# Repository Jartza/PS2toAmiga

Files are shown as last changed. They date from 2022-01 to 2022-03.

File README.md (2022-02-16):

# PS2toAmiga
Simple ATTiny85 based PS/2 to Amiga keyboard protocol converter that fits inside the keyboard.

The project was born as an idea to get small and color-matching keyboard to my old
Commodore Amiga CD32 console, in order to make it more Amiga-like, in use with
TerribleFire 330. I found few projects around The Net which did the same thing but some
of them used old and almost unobtainable ICs with closed firmware and some didn't work
that well.

Many projects used just way too big chip for the job, which I felt was a waste of precious
silicon, as you only need 2 input and 2 output pins for the job - ATTiny85 was chosen as
it's one of my favorite "all 'round" chip for simple tasks.

I wanted the adapter to sit inside the keyboard and use the CD32 AUX-connector (PS/2 style
mini-DIN) as-is for cable.

Of course the keyboard protocol is the same in all Amigas, the pinouts just differ, so this
project can be used to create replacement keyboard for the lost one to your bigger Amigas
as well (like Amiga 2000, 3000 & 4000 etc.)

## How it works

PS/2 keyboard protocol in it's basic level isn't that hard, it is bidirectional synchronous
serial port with clock (CLK) and data (DATA) lines, communicating with PS/2 keyboard using
microcontroller has been done multiple times already - which is why I chose to use
PS2KeyAdvanced library for Arduino to handle that task - I didn't want to re-invent the wheel,
and I had already used PS2KeyAdvanced in earlier projects as well. It also has nice support
for Caps Lock, Num Lock etc.

The keycodes read from PS/2 keyboard using PS2KeyAdvanced are then [translated to the respective
Amiga keycode](convert_table.h) and sent to wire, using
[Amiga keyboard protocol](http://amigadev.elowar.com/read/ADCD_2.1/Hardware_Manual_guide/node0172.html).

The converter-code also keeps track of user pressing CTRL-Amiga-Amiga simultaneously and
implements [resetting the Amiga](http://amigadev.elowar.com/read/ADCD_2.1/Hardware_Manual_guide/node0179.html)
when those keys are pressed. 

There are two different layouts, selectable with Scroll Lock (when Scroll Lock LED is on, second
layout is in use). In first layout, Windows/Menu-keys are mapped to respective
Amiga-keys on both sides of the space bar, Alt-keys are mapped to respective Amiga versions. 
On second layout, Left CTRL is mapped to CTRL, Right CTRL to ALT, ALT to Right Amiga-key. Also
on second layout, F11 and F12 are mapped to Left and Right Amiga-keys.

Mofifying the keyboard mapping should be pretty straight forward, in the table the comment after
keycode denotes the respective key on PS/2 keyboard and the Amiga keycode can be checked from
[this image](images/amigakeys.png). Do not remove values from the table, and do not change the 
order of the items! Only change the HEX Amiga keycode, before the comment.

Code itself is "quick'n'dirty" -style but should be pretty much commented out so you can modify
the internals of it to your own needs - if you have any.

## Installing

See [PS2KeyAdvanced](https://github.com/techpaul/PS2KeyAdvanced) project for install instructions,
for some reason the version 1.0.9 failed to install into my pretty recent Arduino install, but
version 1.0.8 worked as well.

For ATTiny85 support I used [ATTinyCore](https://github.com/SpenceKonde/ATTinyCore), again check
their respective site for install instructions to your Arduino IDE.

After installing ATTinyCore and PS2KeyAdvanced, load the project into your Arduino IDE and 
select following settings:

- **Board:** ATtiny24/45/85 (No bootloader)
- **Chip:** ATtiny85
- **Clock Source**: 16 MHz (PLL)
- **TImer 1 Clock:** CPU frequency
- **LTO:** Enabled
- **millis():** Enabled

#### Steps to install to ATTiny85:

Use whatever ISP programmer you have. I used cheap USBASP programmer with 10 -> 6 pin adapter cable,
having header pins in ISP connector and then pushing the connector into ISP holes (no header soldered)
and keeping them tilted in an angle during programming.

1. Tools -> Burn bootloader (actually only sets fuses, and enables 16MHz PLL clock)
2. Sketch -> Verify/Compile
3. Upload using programmer

You should be done now, if not, verify your programmer connections. I also have had issue sometimes
programming the new parts, which are set to 1MHz default in factory - you might need to change your
Arduino settings to slow down the programmer for Fuse burning.

## Connecting the adapter

Wiring the keyboard to your Amiga and PCB should be pretty obvious in the following diagram:

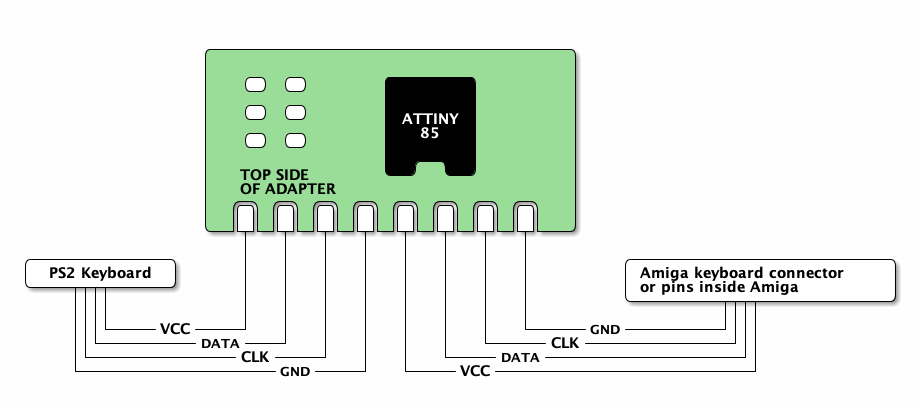
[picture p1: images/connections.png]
Connections


If that is not clear enough, the underside of the PCB has each pin function named.

Several Amigas have different pinouts, Google is your friend here.

**Word of warning:** if you think of re-using the PS/2 keyboard cable, be warned that most of
the keyboards only have 4-wire cable in them and probably the necessary pins are not connected
at all (at least if the Amiga you want to connect to has mini-DIN style keyboard connector).
I solved this issue by ordering PS/2 extension cable and just cutting off the female plug and
then using multimeter to solve cable colors to pins connection. Those extension cables usually
have all the 6 wires connected and it's much easier to use them than to solder those pesky
mini-DIN connectors.

## PCB

PCB files are in [pcb](pcb/) -folder, also including [gerbers](pcb/gerbers/), if you just want
to order the PCB. Schematics are respectively in [schematics](schematics/) -folder.
Bill of Materials, [BOM](schematics/BOM.txt) is also provided.

PCB and Schematics were designed using Eagle 9.6.1 free edition.

### Top side:
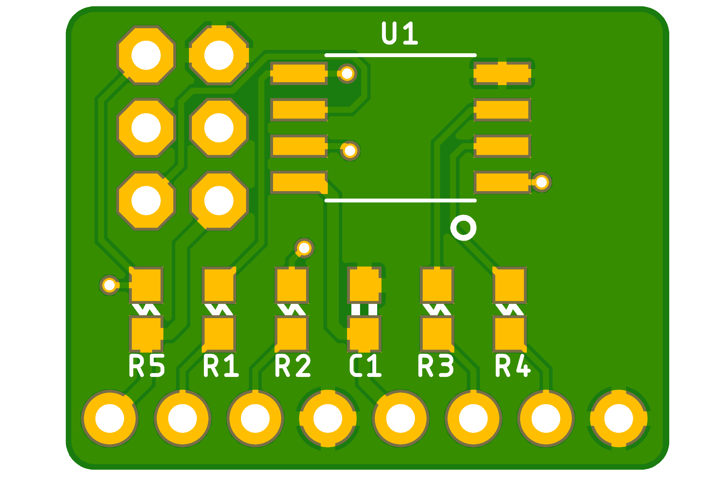
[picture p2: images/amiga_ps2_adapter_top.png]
PCB-TOP


### Bottom side:
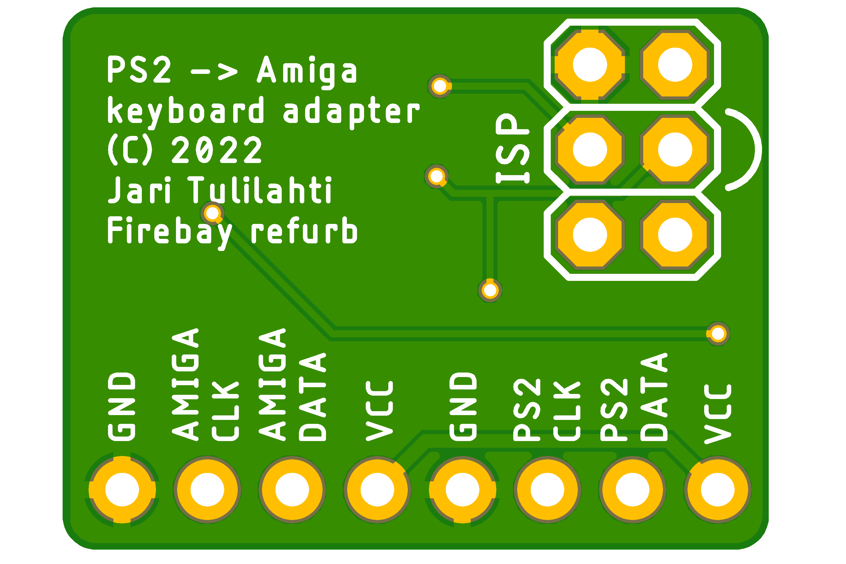
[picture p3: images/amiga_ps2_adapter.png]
PCB-BOTTOM


### Other

Please report any [issues](https://github.com/Jartza/PS2toAmiga/issues) you find with the code!

You can also participate in [discussions](https://github.com/Jartza/PS2toAmiga/discussions) without opening an issue. All enhancement ideas, questions etc. are welcome.

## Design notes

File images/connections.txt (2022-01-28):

                  /------------------------------------\
                  |                               cGRE |
                  |   /-\ /-\       /--------\         |
                  |   \-/ \-/       |        |         |
                  |   /-\ /-\       |cBLK    |         |
                  |   \-/ \-/       | ATTINY |         |
                  |   /-\ /-\       |   85   |         |
                  |   \-/ \-/       |        |         |
                  |                 |  /--\  |         |
                  |   TOP SIDE      \--/  \--/         |
                  |   OF ADAPTER                       |
                  |  /-\ /-\ /-\ /-\ /-\ /-\ /-\ /-\   |
                  |  | | | | | | | | | | | | | | | |   |
                  \--+++-+++-+++-+++-+++-+++-+++-+++---/
                      |   |   |   |   |   |   |   |
/--------------\      |   |   |   |   |   |   |   |         /--------------------------\
| PS2 Keyboard |      |   |   |   |   |   |   |   |         | Amiga keyboard connector |
\----++++------/      |   |   |   |   |   |   |   |         | or pins inside Amiga     |
     ||||             |   |   |   |   |   |   |   |         \---------++++-------------/
     ||||             |   |   |   |   |   |   |   |                   ||||
     |||+-----VCC-----+   |   |   |   |   |   |   +------GND----------+|||
     ||+----------DATA----+   |   |   |   |   +------CLK---------------+||
     |+---------------CLK-----+   |   |   +-----DATA--------------------+|
     +--------------------GND-----+   +-----VCC--------------------------+

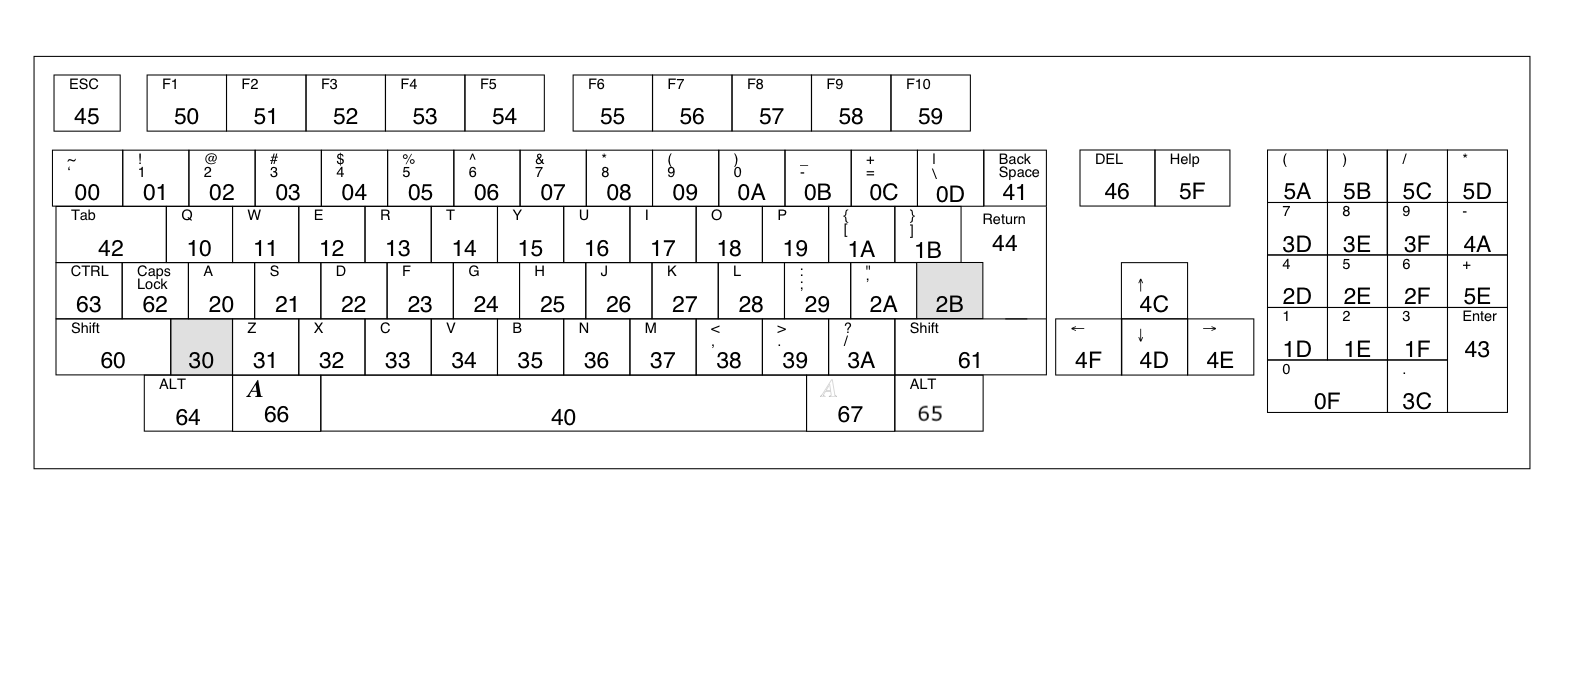
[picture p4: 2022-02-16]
images/amigakeys.png

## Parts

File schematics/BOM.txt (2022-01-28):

Bill of materials for PS2 to Amiga keyboard converter using ATTiny85
====================================================================

Designator                  Part                        Footprint
----------                  ----                        ---------
 U1                         ATTINY85-20SUR              SOIC-8
 R1,R2,R3,R4                Resistor 22-47 ohms         0603
 R5                         Resistor 4.7-10 kohms       0603
 ISP                        2x3 pinheader (NP)          2.54mm pitch
 J2                         1x8 pinheader (NP)          2.54mm pitch
 C1                         Ceramic capacitor 0.1 uF    0603

 NOTE:

 (NP) parts = Not Populated.

 ISP header is only used for programming (from the bottom side of the board!)
 and probably doesn't need to be populated, just press programming cable
 with header pin inserts into the connector holes and tilt a bit during
 ATTiny85 ISP programming.

 J2 is for keyboard connection but as probably this will sit inside the
 keyboard (or in the middle of cable inside stress relief box) you will
 most probably solder the keyboard wires directly to the header.

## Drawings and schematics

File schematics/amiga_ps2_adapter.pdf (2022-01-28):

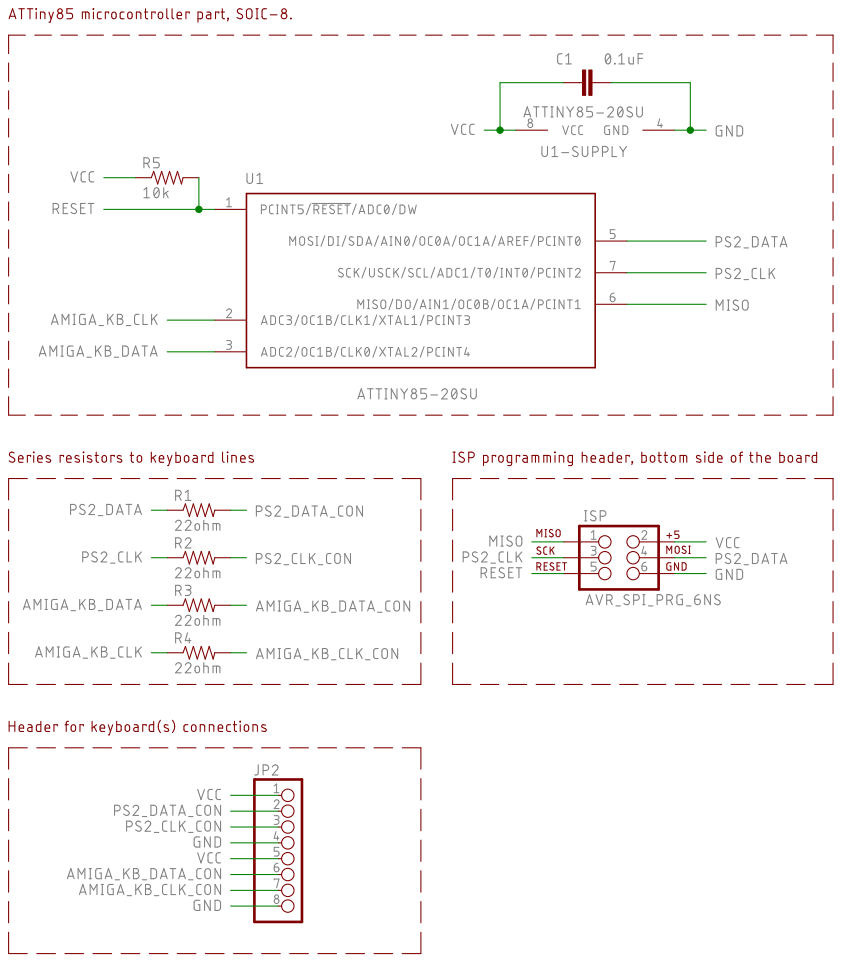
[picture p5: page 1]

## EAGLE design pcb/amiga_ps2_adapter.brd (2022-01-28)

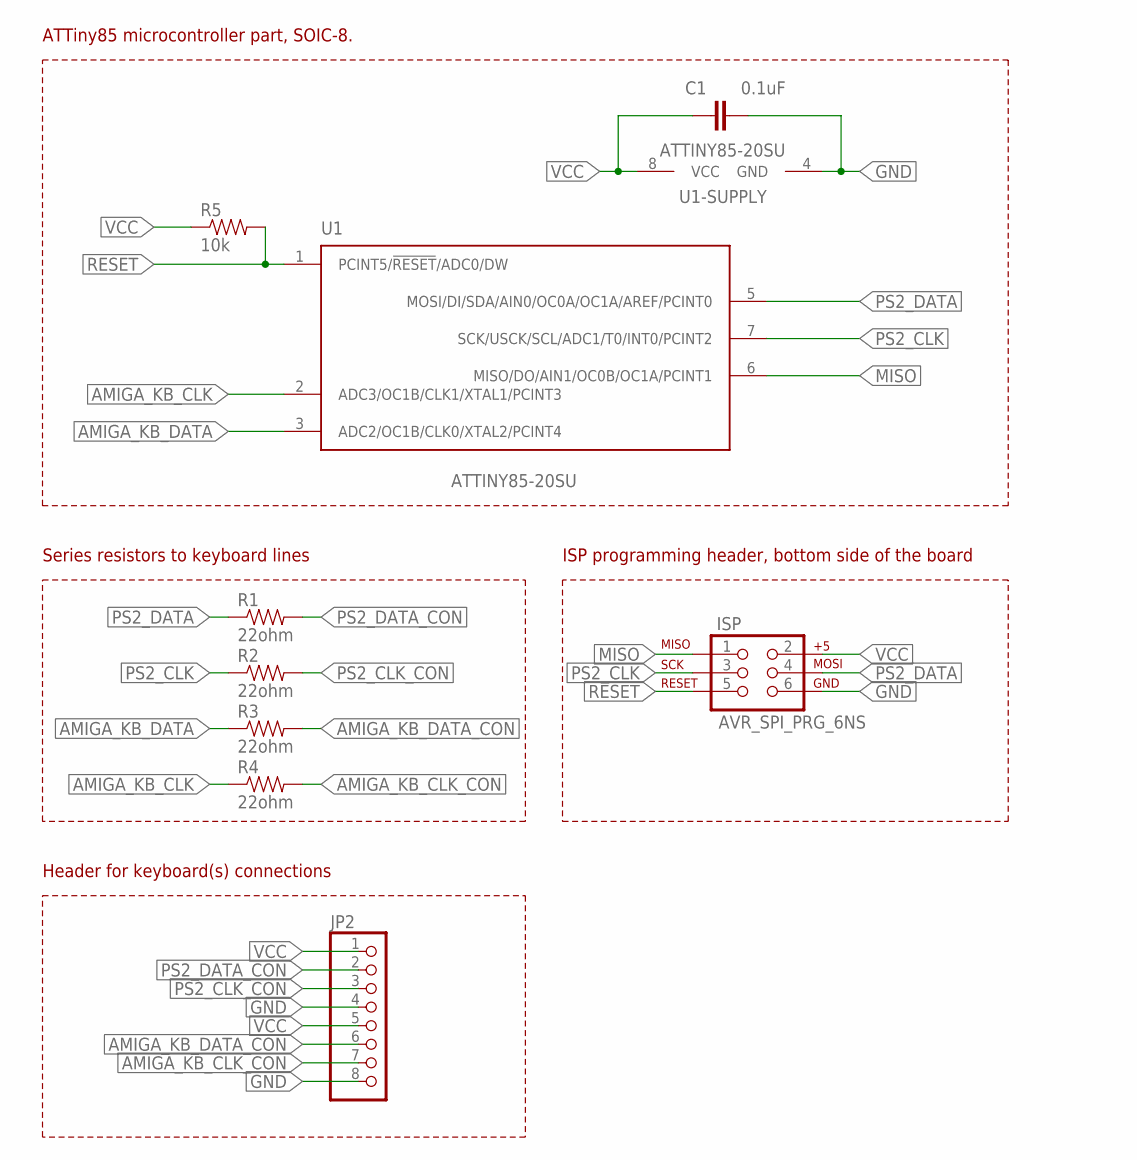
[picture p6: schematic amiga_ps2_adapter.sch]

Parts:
C1: 0.1uF; 0603-CAP
ISP: AVR_SPI_PRG_6NS; 2X3-NS
JP2: HEADER-1X8ROUND; 1X08_ROUND
R1, R2, R3, R4: 22ohm; 0603-RES
R5: 10k; 0603-RES
U1: ATTINY85-20SU; SOIC-8

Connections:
AMIGA_KB_CLK: R4.1, U1.2 (ADC3/OC1B/CLK1/XTAL1/PCINT3)
AMIGA_KB_CLK_CON: JP2.7, R4.2
AMIGA_KB_DATA: R3.1, U1.3 (ADC2/OC1B/CLK0/XTAL2/PCINT4)
AMIGA_KB_DATA_CON: JP2.6, R3.2
GND: C1.2, ISP.6, JP2.4, JP2.8, U1.4 (GND)
MISO: ISP.1, U1.6 (MISO/DO/AIN1/OC0B/OC1A/PCINT1)
PS2_CLK: ISP.3, R2.1, U1.7 (SCK/USCK/SCL/ADC1/T0/INT0/PCINT2)
PS2_CLK_CON: JP2.3, R2.2
PS2_DATA: ISP.4, R1.1, U1.5 (MOSI/DI/SDA/AIN0/OC0A/OC1A/AREF/PCINT0)
PS2_DATA_CON: JP2.2, R1.2
RESET: ISP.5, R5.2, U1.1 (PCINT5/!RESET!/ADC0/DW)
VCC: C1.1, ISP.2, JP2.1, JP2.5, R5.1, U1.8 (VCC)

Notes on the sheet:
ATTiny85 microcontroller part, SOIC-8.
ISP programming header, bottom side of the board
Series resistors to keyboard lines
Header for keyboard(s) connections

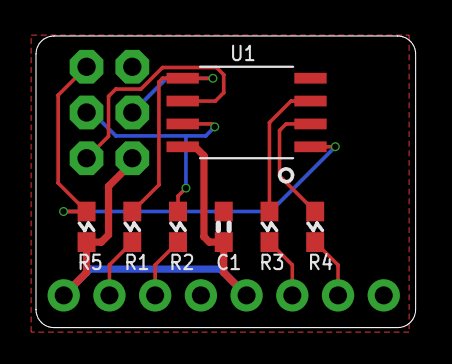
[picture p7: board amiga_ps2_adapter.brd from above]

Board: 2 copper layers, 21.1 x 16.2 mm, 9 parts (1 on the bottom side), 12 nets.

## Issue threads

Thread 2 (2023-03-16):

Question about PS2toAmiga

slappy32, 2023-03-16:
Hello there,
your PS2 to Amiga looks interesting. Can you also make it work in the opposite direction, so that you can connect an
Amiga keyboard to a PS/2 port?

I own an A1200 in a tower upgrade kit by Mikronik. Back in the 90's that company installed an internal PS/2 keyboard interface (= PS/2 port at the back of the tower.) The original A1200 keyboard went into an external chassis that contained an internal adapter to turn the A1200 into a PS/2 keyboard,  while the reset function "Ctrl + leftA + rightA" had been preserved.
But that Mikronik keyboard interface is not the best one, translates only one key-press at a time. And the keys of my A1200 KB have gotten an ugly shade of yellow.
Now I would like to connect one of those nice, rare and black CDTV keyboards to the PS/2 port of my tower and need to convert the Amiga keyboard protocol accordingly. And I can only find some adapters online that convert Amiga keyboards to USB - but my PS/2 port won't understand USB-protocol jsut using one of those cheap USB-to-PS/2 plugs in green or violet.

Further questions:
1. If it is possible to make your adapter work from Amiga keyboard to PS/2 could you do so and offer me one
   ready to use for a good price?
  b) Or at least provide the PCB, that special IC chip flashed with your programm readily,  and provide some short step-by-step
      soldering instructions?

Hope you can help a little.
Greetings,
slappy32

Jartza, 2023-04-05:
Hi. Sorry for delay in answering, I had muted the issues-emails for some reason and only noticed this.

The answer to question is: unfortunately no, it's not easy nor feasible to use this for other-way communication. The PS2 keyboard -reader is using ready library (PS2KeyAdvanced) and the Amiga-side is write-only, implemented as bitbanging protocol. It would require full rewrite of the firmware, and I only wrote this for my own needs to connect a small PS2-keyboard to my Amiga CD32.

Closed 2023-04-05.

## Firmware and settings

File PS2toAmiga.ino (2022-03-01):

/*
   PS2 to Amiga keyboard converter for ATTiny85.

   Uses PS2KeyAdvanced Arduino library to read the PS2 keyboard, which is why you need to
   use Arduino to compile this (and install PS2KeyAdvanced via library manager, see
   https://www.arduino.cc/reference/en/libraries/ps2keyadvanced/)

   Use Boards manager to install ATTinyCore (https://github.com/SpenceKonde/ATTinyCore)
   Settings: 16MHz internal RC osc, enable millis, select chip ATTiny85.

   Code itself is a mix of Arduino-style and low-level AVR code, as this was made to be
   quick'n'dirty solution.

   (C) 2022 by Jari Tulilahti / Firebay Refurb.

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
     You should have received a copy of the GNU Lesser General Public
     License along with this library; if not, write to the Free Software
     Foundation, Inc., 51 Franklin Street, Fifth Floor, Boston, MA  02110-1301
     USA
*/
#include "avr_common.h"
#include "convert_table.h"
#include <avr/delay.h>
#include <PS2KeyAdvanced.h>

// PS2 keyboard pins defined as Arduino pins for PS2KeyAdvanced
#define PS2_DATA 0 // ATTiny85 pin 5
#define PS2_CLK  2 // ATTiny85 pin 7

// Other pins defined as plain AVR macros instead of DigitalWrite()
#define AMI_CLK  PB3 // Amiga CLK ATTiny85 pin 2
#define AMI_DATA PB4 // Amiga DATA ATTiny85 pin 3
#define AMICLK_DIR BITP(DDRB, AMI_CLK)
#define AMICLK_OUT BITP(PORTB, AMI_CLK)
#define AMICLK_IN BITP(PINB, AMI_CLK)
#define AMIDATA_DIR BITP(DDRB, AMI_DATA)
#define AMIDATA_OUT BITP(PORTB, AMI_DATA)
#define AMIDATA_IN BITP(PINB, AMI_DATA)

// Scientifically calculated to be long enough time to wait for ACK (143ms) :D
#define ACK_DELAY 300000


// Macro to send single bit to Amiga KBD lines
#define SENDBIT() do { \
    _delay_us(20); \
    AMIDATA_DIR = code & 0x80 ? DIR_OUT : DIR_IN; \
    _delay_us(20); \
    AMICLK_DIR = DIR_OUT; \
    _delay_us(18); \
    AMICLK_DIR = DIR_IN; \
    code <<= 1; \
  } while(0)

uint16_t code;
uint8_t reset_state = 0b111;
uint8_t scr_lock_state = 0;
PS2KeyAdvanced keyboard;

// Wait for ACK from Amiga. Just busy looping long enough...
// The ACK happens when DATA line goes low within 143ms, but
// it also must come up soonafter...
static inline bool amiga_wait_ack()
{
  bool ack = false;

  // We should wait at least 143ms for ACK
  for (uint32_t i = 0; i < ACK_DELAY; i++)
  {
    if (AMIDATA_IN == LEVEL_LOW)
    {
      ack = true;
      break;
    }
  }

  // Exit early if no ACK
  if (!ack) return false;

  // Wait for line to come up again, or give up
  for (uint32_t i = 0; i < ACK_DELAY; i++)
  {
    if (AMIDATA_IN == LEVEL_HIGH) return true;
  }

  // Timeout
  return false;
}

// Resync with Amiga. According to specs, we just send
// single bit of 1 until we get ACK.
void amiga_resync()
{
  bool ack = false;

  // Repeat syncing until we finally get into sync
  while (!ack)
  {
    // Wait for DATA to rise up
    while (AMIDATA_IN == LEVEL_LOW);

    // Notify computer we have data coming by pulsing DATA line briefly
    AMIDATA_DIR = DIR_OUT;
    _delay_us(18);
    AMIDATA_DIR = DIR_IN;
    _delay_us(118);

    // Just clock single 1 bit to line
    AMIDATA_DIR = DIR_OUT;
    _delay_us(20);
    AMICLK_DIR = DIR_OUT;
    _delay_us(20);
    AMICLK_DIR = DIR_IN;
    _delay_us(20);
    AMIDATA_DIR = DIR_IN;
    ack = amiga_wait_ack();
  }
}

// Force reset of Amiga
void amiga_reset()
{
  // Pull CLK low
  AMICLK_DIR = DIR_OUT;

  // At least 500ms CLK low is needed for reset, use 600ms to be sure.
  // After reset, also clear the PS2 buffer and reset the PS2 keyboard
  // as well.
  _delay_ms(600);

  // Release CLK line
  AMICLK_DIR = DIR_IN;

  // Empty PS2 keyboard buffer
  while (keyboard.available())
  {
    uint8_t c = keyboard.read();
  }

  // Reset the PS2 keyboard
  keyboard.resetKey();
  scr_lock_state = 0;

  // Resync, like in power up.
  amiga_resync();
}

// Send keycode to Amiga KBD pins, return ACK
bool amiga_send_code(uint8_t code, uint8_t pressed)
{
  // Shift Amiga code left and insert pressed status as last bit
  code <<= 1;
  code = code | pressed;

  // Notify computer we have data coming by pulsing DATA line briefly
  AMIDATA_DIR = DIR_OUT;
  _delay_us(20);
  AMIDATA_DIR = DIR_IN;
  _delay_us(100); // Actually 120us but SENDBIT begins with 20us delay

  // Unrolled sending of bits with macro.
  SENDBIT();
  SENDBIT();
  SENDBIT();
  SENDBIT();
  SENDBIT();
  SENDBIT();
  SENDBIT();
  SENDBIT();

  // Finally raise the DATA line
  _delay_us(20);
  AMIDATA_DIR = DIR_IN;

  // Wait for ACK
  bool ack = amiga_wait_ack();
  if (ack) return true;

  // No ACK, need to resync and return false after
  amiga_resync();
  return false;
}

// Initialize everything here
void setup()
{
  // Configure Amiga KBD pins to be inputs by default
  // but set the output status as low. Then we can either
  // float or pull down the pin by switching the data
  // direction register
  AMICLK_DIR = DIR_IN;
  AMICLK_OUT = LEVEL_LOW;
  AMIDATA_DIR = DIR_IN;
  AMIDATA_OUT = LEVEL_LOW;

  // Let us sleep a second as sometimes when plugging the keyboard
  // in, the KDB lines seem to fluctuate a bit, let them stabilize.
  _delay_ms(1000);

  // Wait for Amiga KBD lines to be pulled up
  while (AMIDATA_IN == LEVEL_LOW | AMICLK_IN == LEVEL_LOW);

  // Sync keyboard with Amiga and send
  // power-up stream.
  amiga_resync();
  amiga_send_code(0x7E, 0x01);
  amiga_send_code(0x7F, 0x00);

  // Configure the PS2 library
  keyboard.begin(PS2_DATA, PS2_CLK);
  keyboard.resetKey();
  scr_lock_state = 0;
  keyboard.setNoRepeat(1);
}

// Main loop
void loop( )
{
  // Check if we have new keycodes available in buffer
  if (keyboard.available())
  {
    // Read the next keycode from buffer
    code = keyboard.read();

    uint8_t lb = code & 0xFF;      // Get the lower byte
    uint8_t pressed = code >> 15;  // Extract pressed bit from status bit 15

    // Scroll lock swaps between the two translation tables
    if (lb == 0x02) scr_lock_state = pressed;

    // Translate keycode to Amiga version. Ignore codes bigger then 0xA0 (convert table size)
    // There are two translation tables, Scroll Lock -key switches between the two
    uint8_t ami_c = 0xFF;
    if (lb <= 0xA0) ami_c = pgm_read_byte(&ps2amiga[scr_lock_state][lb]);

    // Keep the pressed state of CTRL-"Amiga"-"Amiga" (Win- or menu-key = Amiga-key) in memory
    // and perform Amiga reset if all three keys are pressed simultaneously.
    if (ami_c == 0x63) reset_state = (reset_state & 0b110) | pressed;        // CTRL
    if (ami_c == 0x66) reset_state = (reset_state & 0b101) | (pressed << 1); // Left Amiga
    if (ami_c == 0x67) reset_state = (reset_state & 0b011) | (pressed << 2); // Right Amiga

    // Reset Amiga if needed, otherwise send keycode to Amiga.
    if (reset_state == 0)
    {
      reset_state = 0b111;
      amiga_reset();
    }
    else if (ami_c != 0xFF) // 0xFF code = do not send anything
    {
      // Send the translated keycode to Amiga KBD lines.
      // Try sending the key until success
      bool ack = false;
      while (!ack)
      {
        ack = amiga_send_code(ami_c, pressed);
      }
    }
  }
}

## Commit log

2022-01-28 Add PCB and Schematics
    [amiga_ps2_adapter.brd, amiga_ps2_adapter.sch]
2022-01-28 Add BOM
2022-01-28 Update BOM
2022-01-29 Fix Arduino compile
2022-02-01 Try to make tabs show in Arduino IDE
2022-02-16 Fix scroll lock state
    [PS2toAmiga.ino]

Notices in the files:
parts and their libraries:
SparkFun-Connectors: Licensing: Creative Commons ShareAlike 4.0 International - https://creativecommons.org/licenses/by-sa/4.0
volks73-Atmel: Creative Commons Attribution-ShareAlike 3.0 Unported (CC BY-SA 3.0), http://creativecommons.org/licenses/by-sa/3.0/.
